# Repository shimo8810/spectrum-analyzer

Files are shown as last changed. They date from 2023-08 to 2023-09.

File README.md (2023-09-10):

# Spectrum Analyzer

This is a stereo 7-band spectrum analyzer utilizing the MSGEQ7.

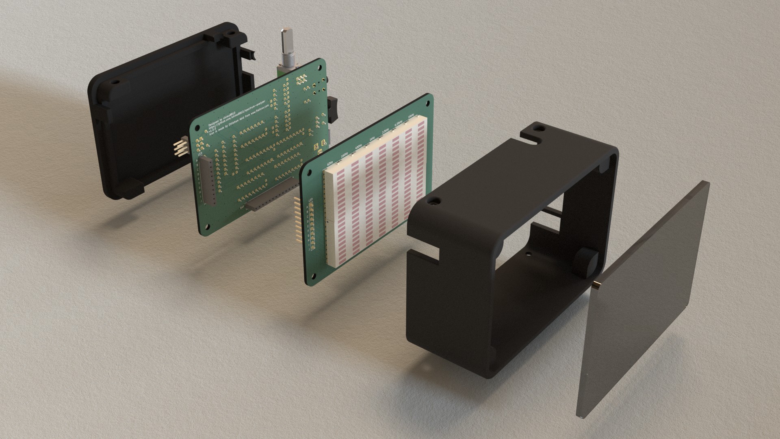
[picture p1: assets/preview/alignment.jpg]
spectrum_analyzer_design


spectrum_analyzer_assembly

## Tools

### LED Matrix Generator

this tool is for generating data for LED matrix.

[LED Matrix Generator Web App](https://shimo8810.github.io/spectrum-analyzer/)
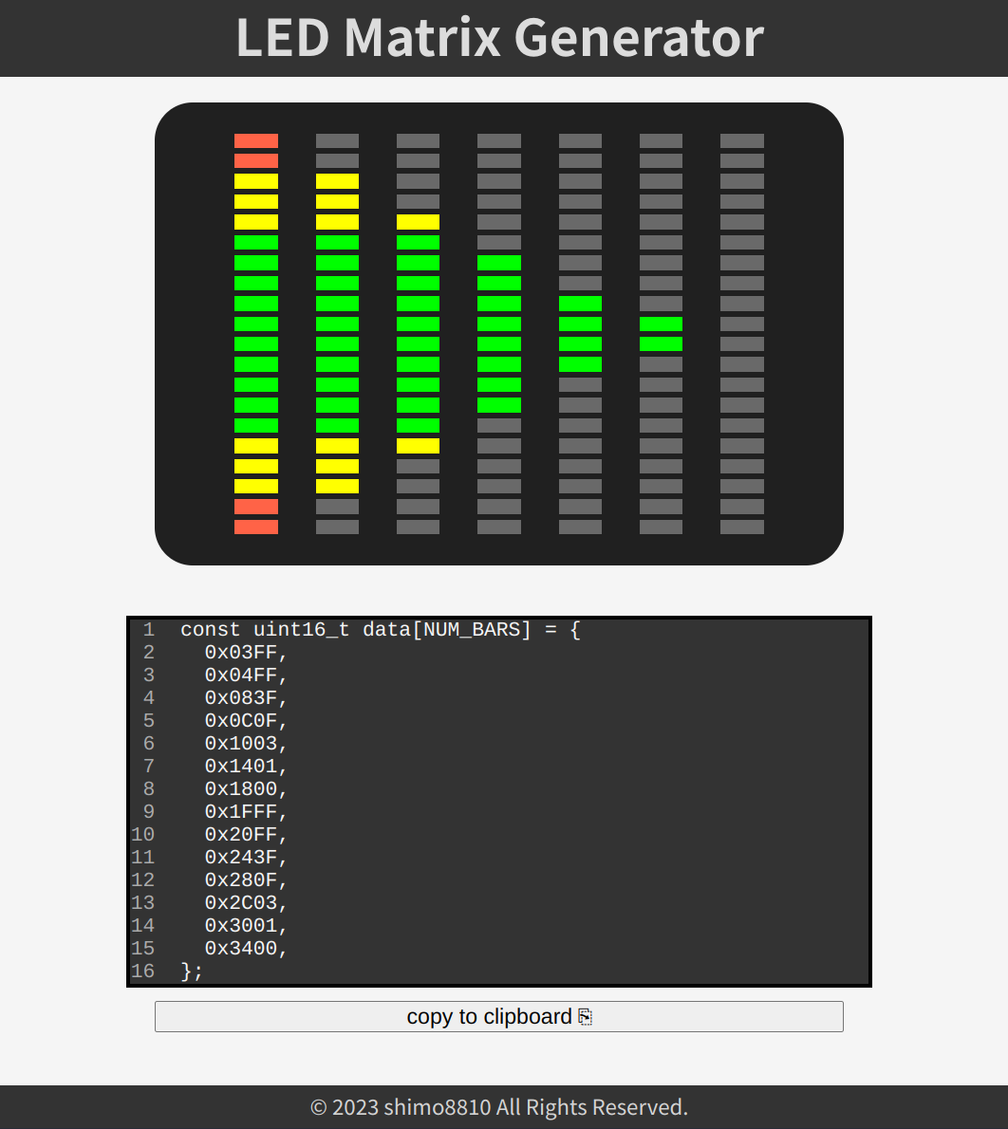
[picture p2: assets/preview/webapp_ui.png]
webapp_ui


## License

- Software: [MIT License](https://choosealicense.com/licenses/mit/)
- Hardware: [CERN Open Hardware License version 2.0](https://choosealicense.com/licenses/cern-ohl-p-2.0/)

## Acknowledgments

- [Equalizer icons created by Ehtisham Abid - Flaticon](https://www.flaticon.com/free-icons/equalizer)

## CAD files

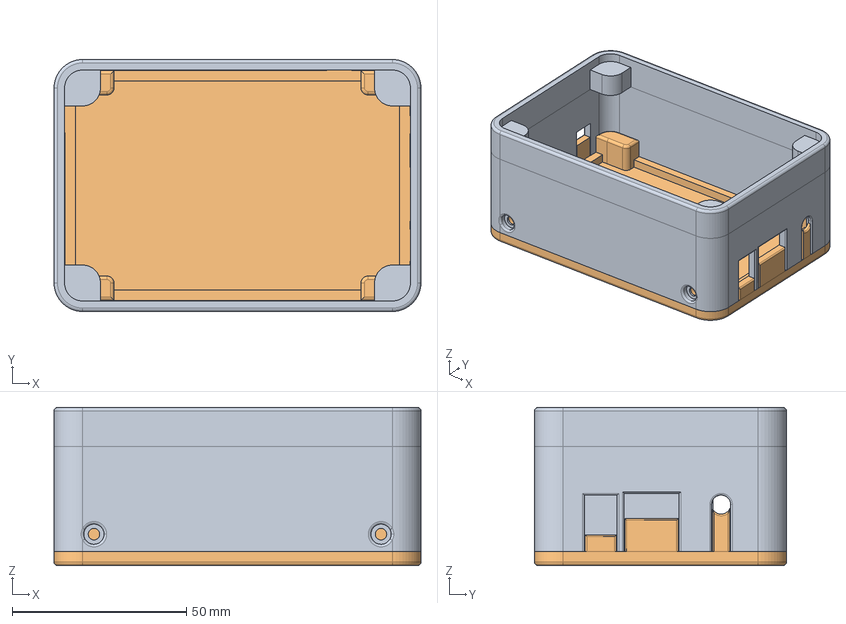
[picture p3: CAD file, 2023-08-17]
3dmodels/spectrum-analyzer.FCStd
105.4 x 72.4 x 45.4 mm
front-body
back-body
Defeatured002

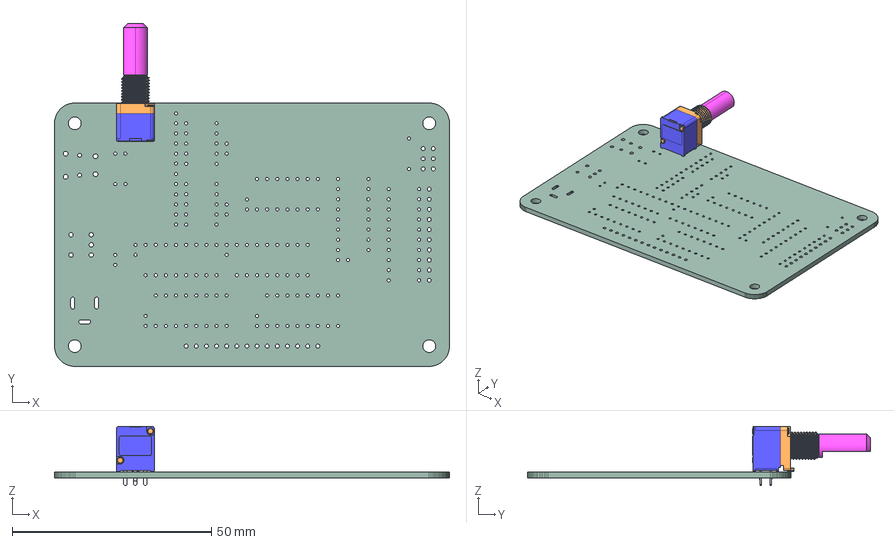
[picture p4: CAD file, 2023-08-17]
assets/spectrum_analyzer_controller.step
99.1 x 86.0 x 14.8 mm
_autosave-spectrum_analyzer_controller PCB

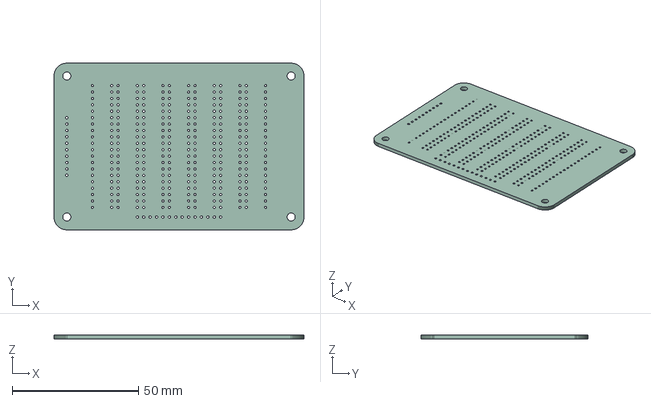
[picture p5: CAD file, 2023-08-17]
assets/spectrum_analyzer_display.step
99.1 x 66.0 x 1.58 mm

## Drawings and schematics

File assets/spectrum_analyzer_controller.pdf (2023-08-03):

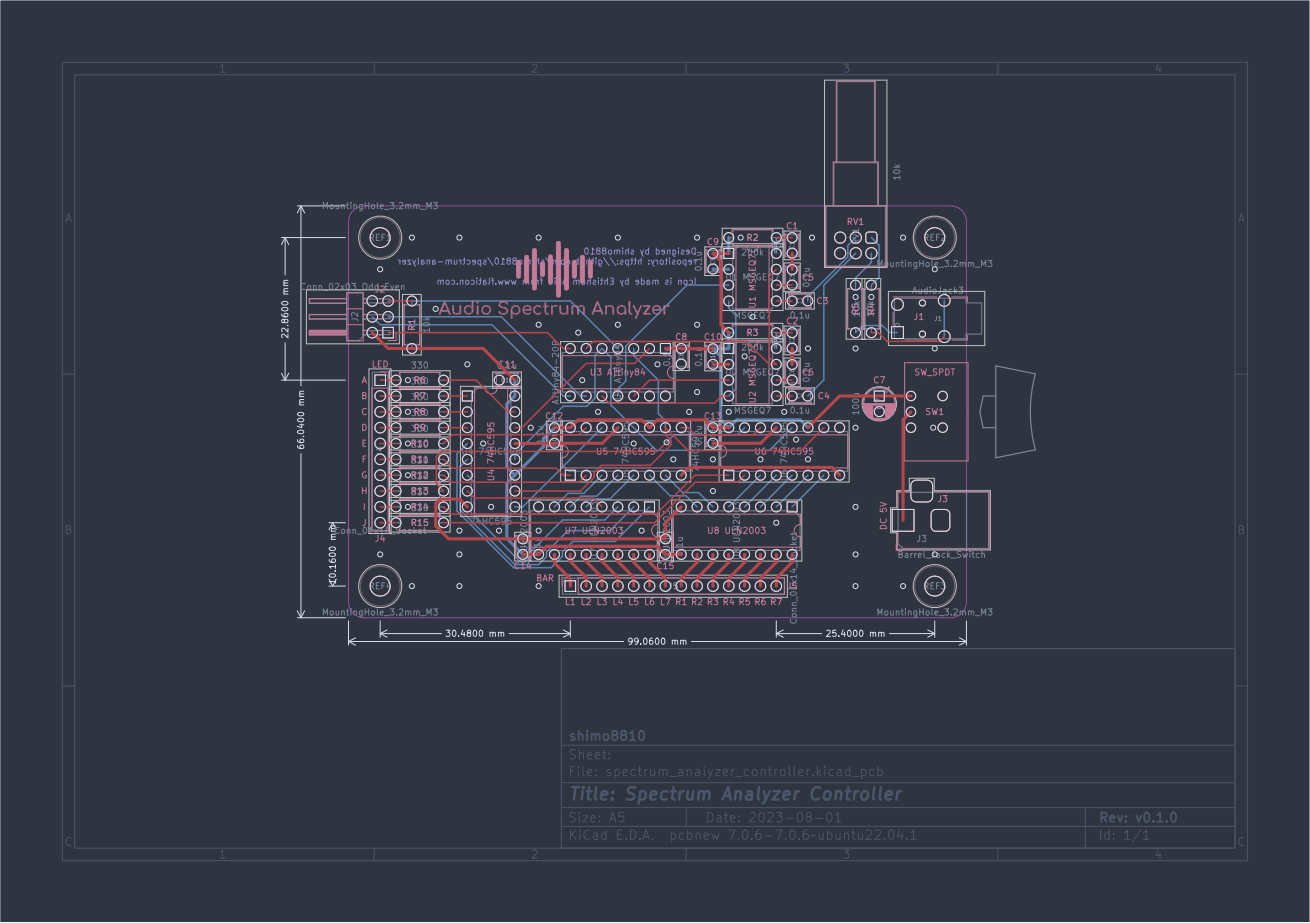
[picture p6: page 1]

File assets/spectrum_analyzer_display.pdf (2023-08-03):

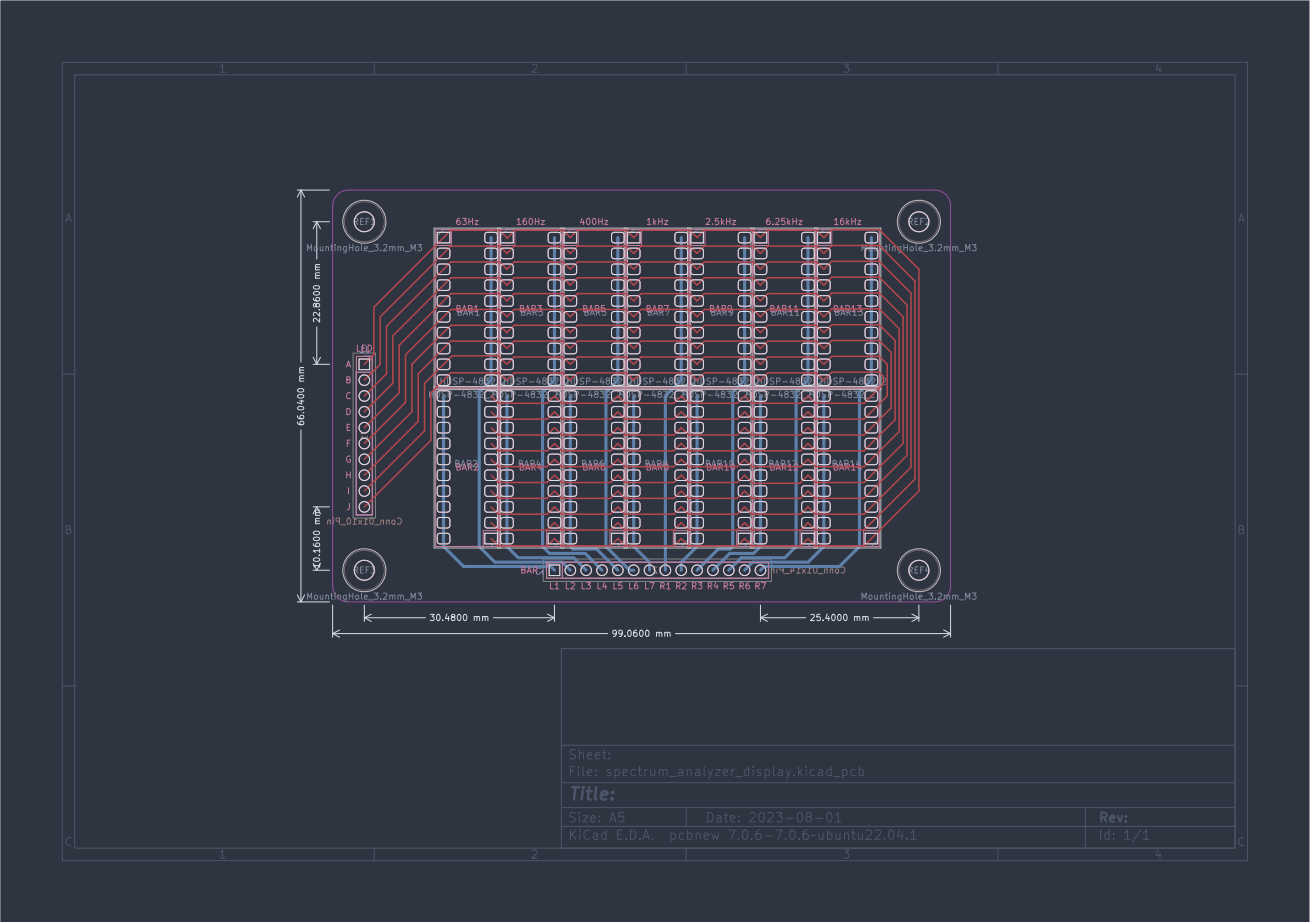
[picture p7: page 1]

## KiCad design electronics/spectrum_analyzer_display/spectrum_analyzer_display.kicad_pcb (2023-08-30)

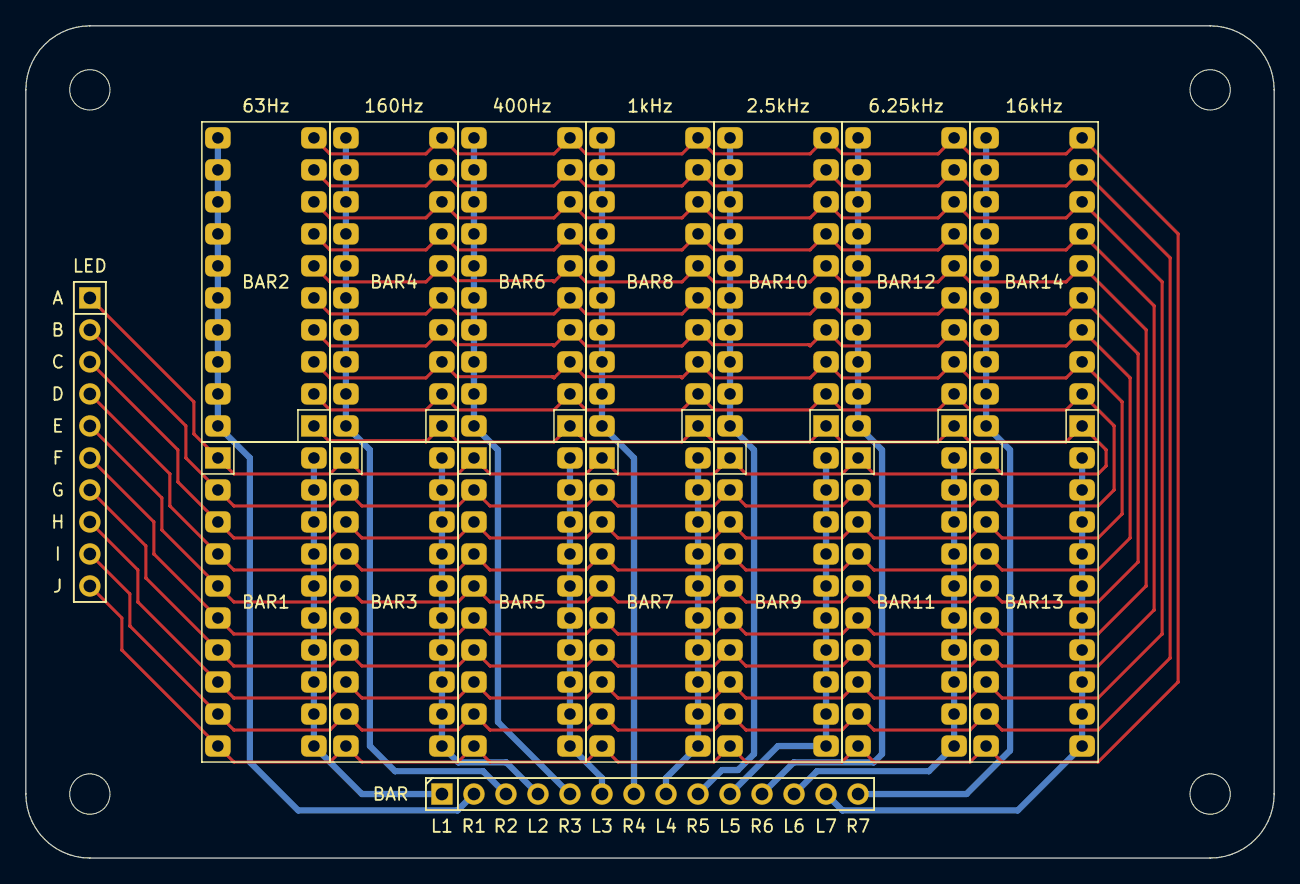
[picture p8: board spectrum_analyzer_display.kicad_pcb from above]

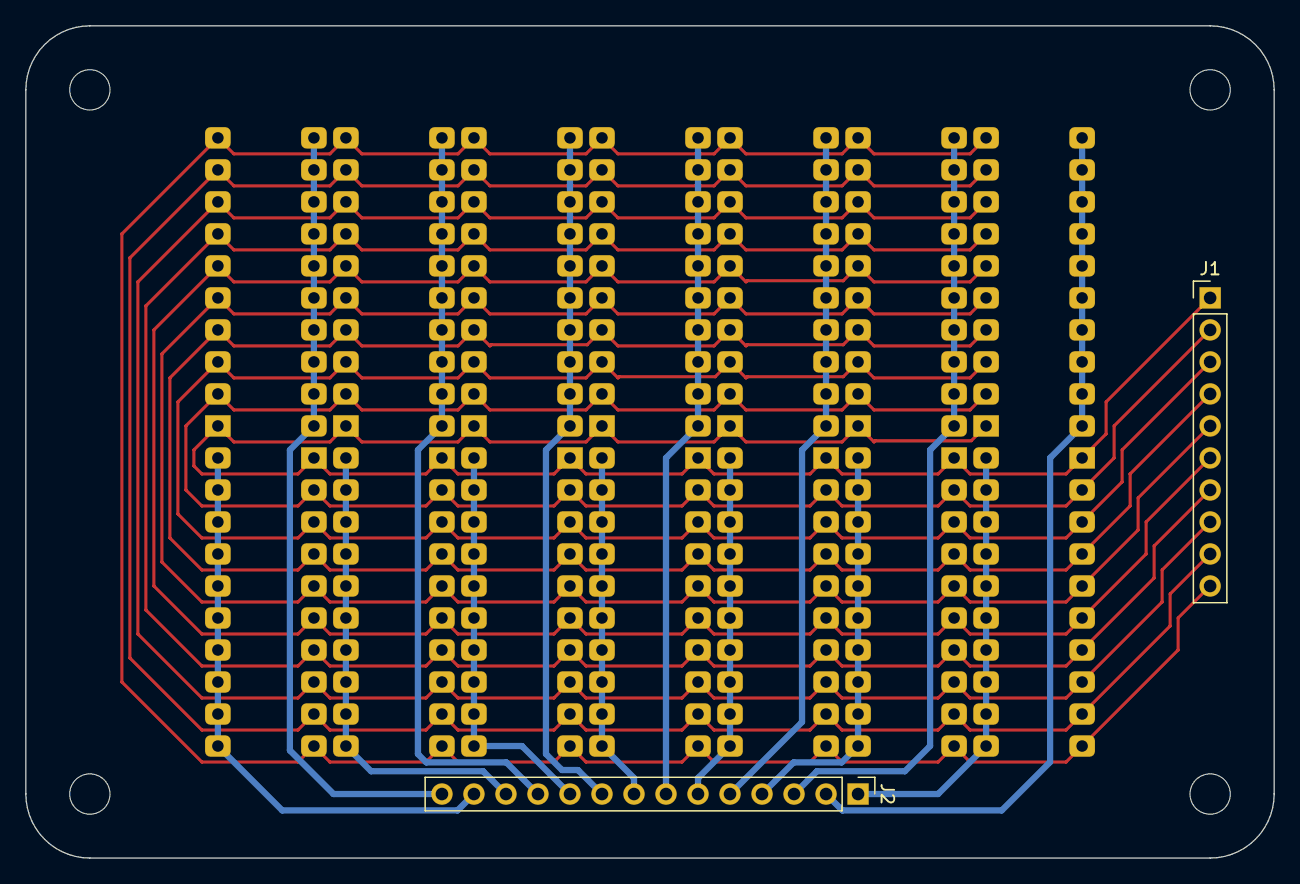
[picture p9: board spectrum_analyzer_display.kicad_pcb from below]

Board: 2 copper layers, 99.1 x 66.0 mm, 20 parts (2 on the bottom side), 24 nets.

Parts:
BAR1, BAR2, BAR3, BAR4, BAR5, BAR6, BAR7, BAR8, BAR9, BAR10, BAR11, BAR12, BAR13, BAR14: HDSP-4832_2; SP_HDSP-4832
J1: Conn_01x10_Pin; PinHeader_1x10_P2.54mm_Vertical
J2: Conn_01x14_Pin; PinHeader_1x14_P2.54mm_Vertical
REF1, REF2, REF3, REF4: MountingHole_3.2mm_M3

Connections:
/A: BAR1.1 (A), BAR2.1 (A), BAR3.1 (A), BAR4.1 (A), BAR5.1 (A), BAR6.1 (A), BAR7.1 (A), BAR8.1 (A), BAR9.1 (A), BAR10.1 (A), BAR11.1 (A), BAR12.1 (A), BAR13.1 (A), BAR14.1 (A), J1.1
/B: BAR1.2 (A), BAR2.2 (A), BAR3.2 (A), BAR4.2 (A), BAR5.2 (A), BAR6.2 (A), BAR7.2 (A), BAR8.2 (A), BAR9.2 (A), BAR10.2 (A), BAR11.2 (A), BAR12.2 (A), BAR13.2 (A), BAR14.2 (A), J1.2
/C: BAR1.3 (A), BAR2.3 (A), BAR3.3 (A), BAR4.3 (A), BAR5.3 (A), BAR6.3 (A), BAR7.3 (A), BAR8.3 (A), BAR9.3 (A), BAR10.3 (A), BAR11.3 (A), BAR12.3 (A), BAR13.3 (A), BAR14.3 (A), J1.3
/D: BAR1.4 (A), BAR2.4 (A), BAR3.4 (A), BAR4.4 (A), BAR5.4 (A), BAR6.4 (A), BAR7.4 (A), BAR8.4 (A), BAR9.4 (A), BAR10.4 (A), BAR11.4 (A), BAR12.4 (A), BAR13.4 (A), BAR14.4 (A), J1.4
/E: BAR1.5 (A), BAR2.5 (A), BAR3.5 (A), BAR4.5 (A), BAR5.5 (A), BAR6.5 (A), BAR7.5 (A), BAR8.5 (A), BAR9.5 (A), BAR10.5 (A), BAR11.5 (A), BAR12.5 (A), BAR13.5 (A), BAR14.5 (A), J1.5
/F: BAR1.6 (A), BAR2.6 (A), BAR3.6 (A), BAR4.6 (A), BAR5.6 (A), BAR6.6 (A), BAR7.6 (A), BAR8.6 (A), BAR9.6 (A), BAR10.6 (A), BAR11.6 (A), BAR12.6 (A), BAR13.6 (A), BAR14.6 (A), J1.6
/G: BAR1.7 (A), BAR2.7 (A), BAR3.7 (A), BAR4.7 (A), BAR5.7 (A), BAR6.7 (A), BAR7.7 (A), BAR8.7 (A), BAR9.7 (A), BAR10.7 (A), BAR11.7 (A), BAR12.7 (A), BAR13.7 (A), BAR14.7 (A), J1.7
/H: BAR1.8 (A), BAR2.8 (A), BAR3.8 (A), BAR4.8 (A), BAR5.8 (A), BAR6.8 (A), BAR7.8 (A), BAR8.8 (A), BAR9.8 (A), BAR10.8 (A), BAR11.8 (A), BAR12.8 (A), BAR13.8 (A), BAR14.8 (A), J1.8
/I: BAR1.9 (A), BAR2.9 (A), BAR3.9 (A), BAR4.9 (A), BAR5.9 (A), BAR6.9 (A), BAR7.9 (A), BAR8.9 (A), BAR9.9 (A), BAR10.9 (A), BAR11.9 (A), BAR12.9 (A), BAR13.9 (A), BAR14.9 (A), J1.9
/J: BAR1.10 (A), BAR2.10 (A), BAR3.10 (A), BAR4.10 (A), BAR5.10 (A), BAR6.10 (A), BAR7.10 (A), BAR8.10 (A), BAR9.10 (A), BAR10.10 (A), BAR11.10 (A), BAR12.10 (A), BAR13.10 (A), BAR14.10 (A), J1.10
/LEFT_1: BAR1.11 (K), BAR1.12 (K), BAR1.13 (K), BAR1.14 (K), BAR1.15 (K), BAR1.16 (K), BAR1.17 (K), BAR1.18 (K), BAR1.19 (K), BAR1.20 (K), J2.1
/LEFT_2: BAR3.11 (K), BAR3.12 (K), BAR3.13 (K), BAR3.14 (K), BAR3.15 (K), BAR3.16 (K), BAR3.17 (K), BAR3.18 (K), BAR3.19 (K), BAR3.20 (K), J2.4
/LEFT_3: BAR5.11 (K), BAR5.12 (K), BAR5.13 (K), BAR5.14 (K), BAR5.15 (K), BAR5.16 (K), BAR5.17 (K), BAR5.18 (K), BAR5.19 (K), BAR5.20 (K), J2.6
/LEFT_4: BAR7.11 (K), BAR7.12 (K), BAR7.13 (K), BAR7.14 (K), BAR7.15 (K), BAR7.16 (K), BAR7.17 (K), BAR7.18 (K), BAR7.19 (K), BAR7.20 (K), J2.8
/LEFT_5: BAR9.11 (K), BAR9.12 (K), BAR9.13 (K), BAR9.14 (K), BAR9.15 (K), BAR9.16 (K), BAR9.17 (K), BAR9.18 (K), BAR9.19 (K), BAR9.20 (K), J2.10
/LEFT_6: BAR11.11 (K), BAR11.12 (K), BAR11.13 (K), BAR11.14 (K), BAR11.15 (K), BAR11.16 (K), BAR11.17 (K), BAR11.18 (K), BAR11.19 (K), BAR11.20 (K), J2.12
/LEFT_7: BAR13.11 (K), BAR13.12 (K), BAR13.13 (K), BAR13.14 (K), BAR13.15 (K), BAR13.16 (K), BAR13.17 (K), BAR13.18 (K), BAR13.19 (K), BAR13.20 (K), J2.13
/RIGHT_1: BAR2.11 (K), BAR2.12 (K), BAR2.13 (K), BAR2.14 (K), BAR2.15 (K), BAR2.16 (K), BAR2.17 (K), BAR2.18 (K), BAR2.19 (K), BAR2.20 (K), J2.2
/RIGHT_2: BAR4.11 (K), BAR4.12 (K), BAR4.13 (K), BAR4.14 (K), BAR4.15 (K), BAR4.16 (K), BAR4.17 (K), BAR4.18 (K), BAR4.19 (K), BAR4.20 (K), J2.3
/RIGHT_3: BAR6.11 (K), BAR6.12 (K), BAR6.13 (K), BAR6.14 (K), BAR6.15 (K), BAR6.16 (K), BAR6.17 (K), BAR6.18 (K), BAR6.19 (K), BAR6.20 (K), J2.5
/RIGHT_4: BAR8.11 (K), BAR8.12 (K), BAR8.13 (K), BAR8.14 (K), BAR8.15 (K), BAR8.16 (K), BAR8.17 (K), BAR8.18 (K), BAR8.19 (K), BAR8.20 (K), J2.7
/RIGHT_5: BAR10.11 (K), BAR10.12 (K), BAR10.13 (K), BAR10.14 (K), BAR10.15 (K), BAR10.16 (K), BAR10.17 (K), BAR10.18 (K), BAR10.19 (K), BAR10.20 (K), J2.9
/RIGHT_6: BAR12.11 (K), BAR12.12 (K), BAR12.13 (K), BAR12.14 (K), BAR12.15 (K), BAR12.16 (K), BAR12.17 (K), BAR12.18 (K), BAR12.19 (K), BAR12.20 (K), J2.11
/RIGHT_7: BAR14.11 (K), BAR14.12 (K), BAR14.13 (K), BAR14.14 (K), BAR14.15 (K), BAR14.16 (K), BAR14.17 (K), BAR14.18 (K), BAR14.19 (K), BAR14.20 (K), J2.14

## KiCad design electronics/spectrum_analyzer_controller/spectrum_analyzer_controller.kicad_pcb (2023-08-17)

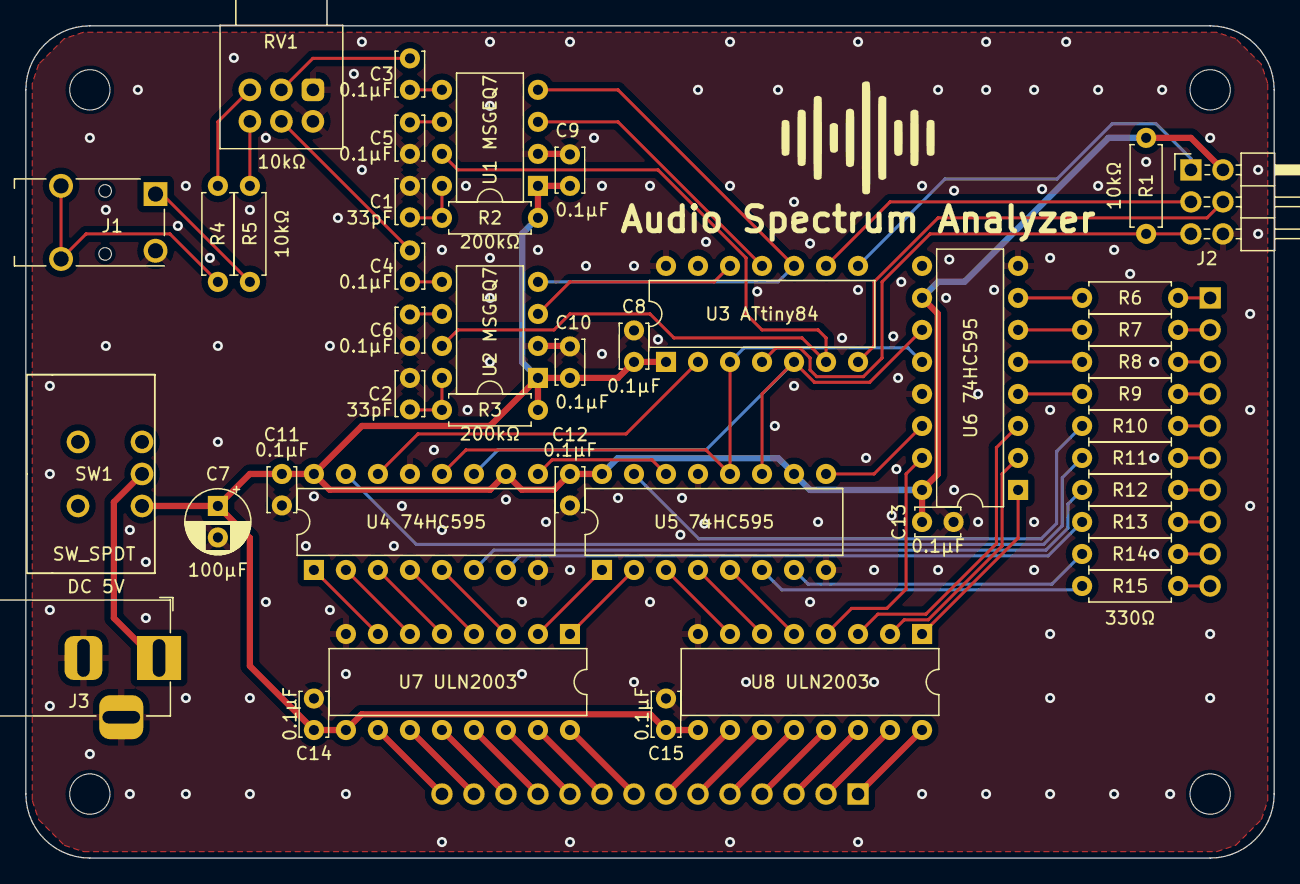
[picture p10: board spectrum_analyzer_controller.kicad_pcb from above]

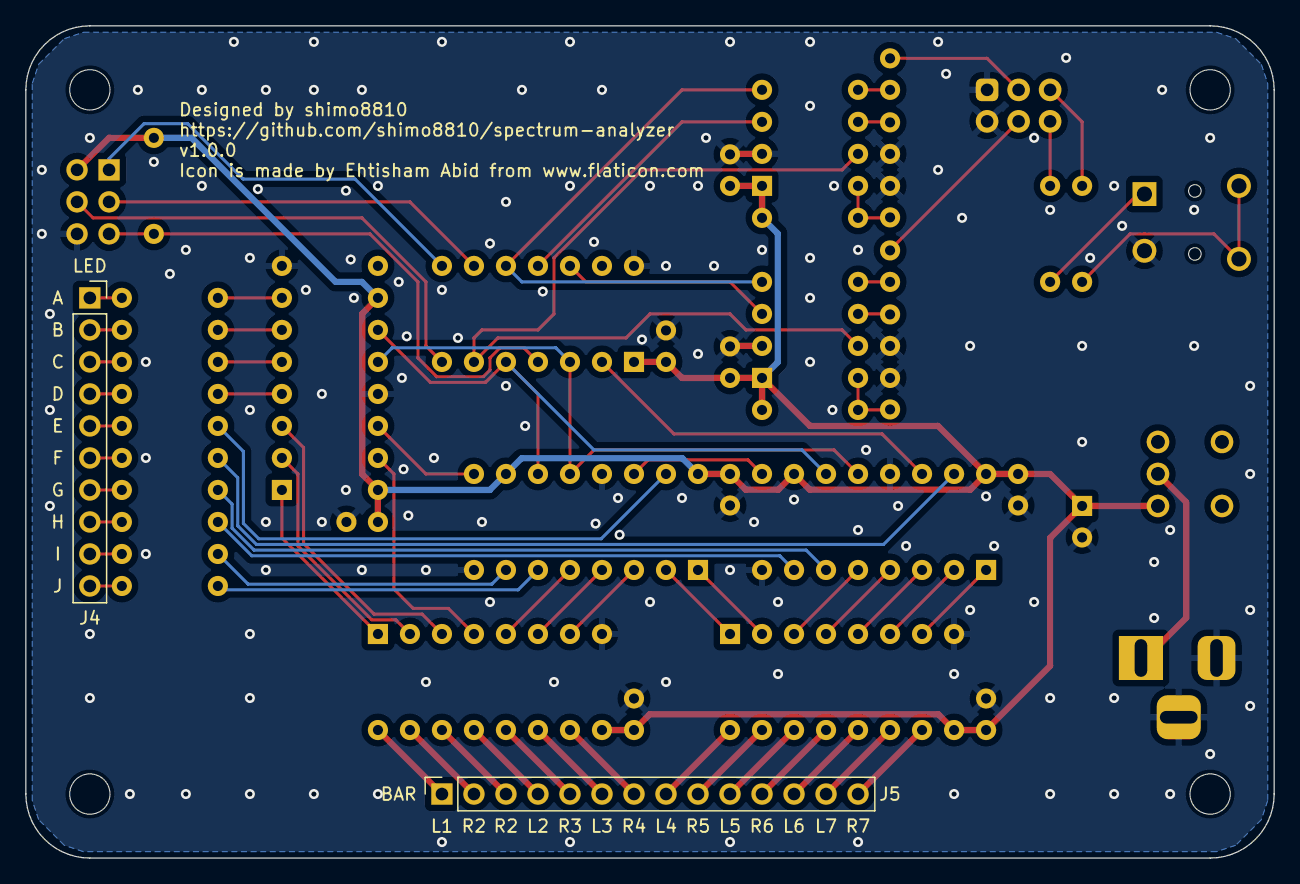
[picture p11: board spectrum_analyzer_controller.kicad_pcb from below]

Board: 2 copper layers, 99.1 x 66.0 mm, 50 parts (2 on the bottom side), 76 nets.

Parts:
C1, C2: 33p; C_Disc_D3.4mm_W2.1mm_P2.50mm
C3, C4, C5, C6, C8, C9, C10, C11, C12, C13, C14, C15: 0.1u; C_Disc_D3.4mm_W2.1mm_P2.50mm
C7: 100u; CP_Radial_D5.0mm_P2.50mm
G1: LOGO; equalizer_icon
J1: AudioJack3; Jack_3.5mm_Switronic_ST-005-G_horizontal
J2: Conn_02x03_Odd_Even; PinHeader_2x03_P2.54mm_Horizontal
J3: Barrel_Jack_Switch; BarrelJack_Horizontal
J4: Conn_01x10_Socket; PinSocket_1x10_P2.54mm_Vertical
J5: Conn_01x14_Socket; PinSocket_1x14_P2.54mm_Vertical
R1, R4, R5: 10k; SP_R_Axial_DIN0207_L6.3mm_D2.5mm_P7.62mm_Horizontal
R2, R3: 200k; SP_R_Axial_DIN0207_L6.3mm_D2.5mm_P7.62mm_Horizontal
R6, R7, R8, R9, R10, R11, R12, R13, R14, R15: 330; SP_R_Axial_DIN0207_L6.3mm_D2.5mm_P7.62mm_Horizontal
REF1, REF2, REF3, REF4: MountingHole_3.2mm_M3
RV1: 10k; Potentiometer_Alps_RK097_Dual_Horizontal
SW1: SW_SPDT; 4MS1R202M6QES
U1 MSGEQ7, U2 MSGEQ7: MSGEQ7; DIP-8_W7.62mm
U3 ATtiny84: ATtiny84-20P; DIP-14_W7.62mm
U4 74HC595, U5 74HC595, U6 74HC595: 74HC595; DIP-16_W7.62mm
U7 ULN2003, U8 ULN2003: ULN2003; DIP-16_W7.62mm

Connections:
+5V: C7.1, C8.1, C9.1, C10.1, C11.1, C12.1, C13.1, C14.1, C15.1, J2.2, R1.1, R2.1, R3.1, SW1.1 (A), U1 MSGEQ7.1 (VDD), U2 MSGEQ7.1 (VDD), U3 ATtiny84.1 (VCC), U4 74HC595.10 (~SRCLR), U4 74HC595.16 (VCC), U5 74HC595.10 (~SRCLR), U5 74HC595.16 (VCC), U6 74HC595.10 (~SRCLR), U6 74HC595.16 (VCC), U7 ULN2003.9 (COM), U8 ULN2003.9 (COM)
/GEQ_RESET: U1 MSGEQ7.7 (RESET), U2 MSGEQ7.7 (RESET), U3 ATtiny84.6 (PA7)
/ICSP_CLOCK: J2.3, U3 ATtiny84.9 (PA4)
/ICSP_MISO: J2.1, U3 ATtiny84.8 (PA5)
/ICSP_MOSI: J2.4, U3 ATtiny84.7 (PA6)
/LED_A: R6.1, U6 74HC595.7 (QH)
/LED_B: R7.1, U6 74HC595.6 (QG)
/LED_C: R8.1, U6 74HC595.5 (QF)
/LED_CLOCK: U3 ATtiny84.5 (PB2), U4 74HC595.11 (SRCLK), U5 74HC595.11 (SRCLK), U6 74HC595.11 (SRCLK)
/LED_D: R9.1, U6 74HC595.4 (QE)
/LED_DATA: U3 ATtiny84.2 (XTAL1/PB0), U4 74HC595.14 (SER)
/LED_E: R10.1, U5 74HC595.15 (QA)
/LED_F: R11.1, U4 74HC595.15 (QA)
/LED_G: R12.1, U4 74HC595.6 (QG)
/LED_H: R13.1, U4 74HC595.7 (QH)
/LED_I: R14.1, U5 74HC595.7 (QH)
/LED_J: R15.1, U5 74HC595.6 (QG)
/LED_LATCH: U3 ATtiny84.3 (XTAL2/PB1), U4 74HC595.12 (RCLK), U5 74HC595.12 (RCLK), U6 74HC595.12 (RCLK)
/LEFT_1: J5.1, U8 ULN2003.16 (O1)
/LEFT_2: J5.4, U8 ULN2003.13 (O4)
/LEFT_3: J5.6, U8 ULN2003.11 (O6)
/LEFT_4: J5.8, U7 ULN2003.16 (O1)
/LEFT_5: J5.10, U7 ULN2003.14 (O3)
/LEFT_6: J5.12, U7 ULN2003.12 (O5)
/LEFT_7: J5.13, U7 ULN2003.11 (O6)
/LEFT_IN: C3.1, U1 MSGEQ7.5 (IN)
/LEFT_OUT: U1 MSGEQ7.3 (OUT), U3 ATtiny84.11 (PA2)
/RESET: J2.5, R1.2, U3 ATtiny84.4 (~RESET/PB3)
/RIGHT_1: J5.2, U8 ULN2003.15 (O2)
/RIGHT_2: J5.3, U8 ULN2003.14 (O3)
/RIGHT_3: J5.5, U8 ULN2003.12 (O5)
/RIGHT_4: J5.7, U8 ULN2003.10 (O7)
/RIGHT_5: J5.9, U7 ULN2003.15 (O2)
/RIGHT_6: J5.11, U7 ULN2003.13 (O4)
/RIGHT_7: J5.14, U7 ULN2003.10 (O7)
/RIGHT_IN: C4.1, U2 MSGEQ7.5 (IN)
/RIGHT_OUT: U2 MSGEQ7.3 (OUT), U3 ATtiny84.12 (PA1)
/STROBE: U1 MSGEQ7.4 (STROBE), U2 MSGEQ7.4 (STROBE), U3 ATtiny84.10 (PA3)
GND: C1.2, C2.2, C5.2, C6.2, C7.2, C8.2, C9.2, C10.2, C11.2, C12.2, C13.2, C14.2, C15.2, J1.S, J2.6, J3.2, J3.3, RV1.1, RV1.4, U1 MSGEQ7.2 (VSS), U2 MSGEQ7.2 (VSS), U3 ATtiny84.14 (GND), U4 74HC595.8 (GND), U4 74HC595.13 (~OE), U5 74HC595.8 (GND), U5 74HC595.13 (~OE), U6 74HC595.8 (GND), U6 74HC595.13 (~OE), U7 ULN2003.8 (GND), U8 ULN2003.8 (GND)
unnamed: C3.2, RV1.2
unnamed: C4.2, RV1.5
unnamed: J1.R, R5.1
unnamed: J1.T, R4.2
unnamed: J4.1, R6.2
unnamed: J4.2, R7.2
unnamed: J4.3, R8.2
unnamed: J4.4, R9.2
unnamed: J4.5, R10.2
unnamed: J4.6, R11.2
unnamed: J4.7, R12.2
unnamed: J4.8, R13.2
unnamed: J4.9, R14.2
unnamed: J4.10, R15.2
unnamed: R4.1, RV1.3
unnamed: R5.2, RV1.6
unnamed: C1.1, R2.2, U1 MSGEQ7.8 (CKIN)
unnamed: C5.1, U1 MSGEQ7.6 (GND)
unnamed: C2.1, R3.2, U2 MSGEQ7.8 (CKIN)
unnamed: C6.1, U2 MSGEQ7.6 (GND)
unnamed: U4 74HC595.1 (QB), U7 ULN2003.7 (I7)
unnamed: U4 74HC595.2 (QC), U7 ULN2003.6 (I6)
unnamed: U4 74HC595.3 (QD), U7 ULN2003.5 (I5)
unnamed: U4 74HC595.4 (QE), U7 ULN2003.4 (I4)
unnamed: U4 74HC595.5 (QF), U7 ULN2003.3 (I3)
unnamed: U4 74HC595.9 (QH'), U5 74HC595.14 (SER)
unnamed: U5 74HC595.1 (QB), U7 ULN2003.2 (I2)
unnamed: U5 74HC595.2 (QC), U7 ULN2003.1 (I1)
unnamed: U5 74HC595.3 (QD), U8 ULN2003.7 (I7)
unnamed: U5 74HC595.4 (QE), U8 ULN2003.6 (I6)
unnamed: U5 74HC595.5 (QF), U8 ULN2003.5 (I5)
unnamed: U5 74HC595.9 (QH'), U6 74HC595.14 (SER)
unnamed: U6 74HC595.15 (QA), U8 ULN2003.4 (I4)
unnamed: U6 74HC595.1 (QB), U8 ULN2003.1 (I1)
unnamed: U6 74HC595.2 (QC), U8 ULN2003.2 (I2)
unnamed: U6 74HC595.3 (QD), U8 ULN2003.3 (I3)
VDC: J3.1, SW1.2 (B)

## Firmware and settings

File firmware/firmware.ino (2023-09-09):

// PINOUT
const uint8_t DATA_PIN = 10;
const uint8_t LATCH_PIN = 9;
const uint8_t CLOCK_PIN = 8;
const uint8_t ROUT_PIN = A1;
const uint8_t LOUT_PIN = A2;
const uint8_t STROBE_PIN = 3;
const uint8_t RESET_PIN = 7;

// LED Matrix constants
const uint8_t NUM_LEVEL = 10;
const uint8_t NUM_BAND = 7;
const uint8_t NUM_BARS = NUM_BAND * 2;

// LED Matrix data
uint32_t MATRIX_DATA[NUM_BARS];

// LED Matrix max level
uint8_t MAX_LEVEL[NUM_BARS];
uint8_t MAX_COUNT[NUM_BARS];
uint8_t MAX_DOWN[NUM_BARS];

/**
 * @brief update led matrix using shift register
 *
 * @param data_pin
 * @param latch_pin
 * @param clock_pin
 * @param data
 */
void updateLedMatrix(const uint8_t data_pin, const uint8_t latch_pin,
                     const uint8_t clock_pin, const uint32_t &data) {
  digitalWrite(latch_pin, LOW);
  for (int i = 0; i < (NUM_LEVEL + NUM_BARS); ++i) {
    digitalWrite(data_pin, (data >> i) & 1);
    digitalWrite(clock_pin, HIGH);
    digitalWrite(clock_pin, LOW);
  }
  digitalWrite(latch_pin, HIGH);
}

/**
 * @brief convert data to led matrix format
 *
 * @param data
 * @return uint32_t
 */
uint32_t convertData(const uint16_t data) {
  // LED bar bits position
  static const uint32_t bar_pos[] = {
      0x20, 0x10, 0x400, 0x1000, 0x4000,  0x80000,  0x400000,
      0x40, 0x80, 0x800, 0x2000, 0x40000, 0x100000, 0x200000};

  // LED bits position
  static const uint32_t led_pos[] = {
      0x1, 0x2, 0x4, 0x8, 0x8000, 0x800000, 0x20000, 0x10000, 0x100, 0x200,
  };

  uint32_t bits = bar_pos[data >> NUM_LEVEL];

  for (uint32_t i = 0; i < NUM_LEVEL; ++i) {
    if ((data >> i) & 1) {
      bits += led_pos[i];
    }
  }
  return bits;
}

/**
 * @brief create led matrix data
 *
 * @param level
 * @param bar
 * @return uint32_t
 */
uint32_t createData(const uint8_t level, const uint8_t bar) {
  uint16_t data = (bar << NUM_LEVEL) + (0x03FF >> (NUM_LEVEL - level));

  if (MAX_LEVEL[bar] <= level) {
    // 最大を更新してカウント値と落下状態を更新
    MAX_LEVEL[bar] = level;
    MAX_DOWN[bar] = 0;
    MAX_COUNT[bar] = 0;
  } else if (MAX_LEVEL[bar] && ++MAX_COUNT[bar] >= 10) {
    if (MAX_LEVEL[bar] >= 5) {
      MAX_DOWN[bar] = 1;
    }
    MAX_LEVEL[bar] -= 1;
    MAX_COUNT[bar] = 10;
  }
  if (MAX_LEVEL[bar] >= 5 || (MAX_LEVEL[bar] && MAX_DOWN[bar])) {
    data |= 1 << (MAX_LEVEL[bar] - 1);
  }

  return convertData(data);
}

/**
 * @brief logscale function
 *
 * @param value
 * @return uint8_t
 */
uint8_t logscale(const int &value) {
  static const int lut[] = {141, 168, 201, 243, 296, 362, 446, 552, 685, 852};
  // static const int lut[] = {65, 85, 112, 148, 195, 257, 338, 446, 589,
  // 777};
  uint8_t level = 0;
  for (level = 0; level < NUM_LEVEL; ++level) {
    if (value < lut[level]) {
      break;
    }
  }
  return level;
}

/**
 * @brief setup function
 *
 */
void setup() {
  // setup led matrix
  pinMode(DATA_PIN, OUTPUT);
  pinMode(LATCH_PIN, OUTPUT);
  pinMode(CLOCK_PIN, OUTPUT);

  // clear LED Matrix
  updateLedMatrix(DATA_PIN, LATCH_PIN, CLOCK_PIN, 0);
  delay(100);

  // setup msgeq7
  pinMode(RESET_PIN, OUTPUT);
  pinMode(STROBE_PIN, OUTPUT);

  // init msgeq7
  digitalWrite(STROBE_PIN, LOW);
  delay(1);
  digitalWrite(RESET_PIN, HIGH);
  delay(1);
  digitalWrite(STROBE_PIN, HIGH);
  delay(1);
  digitalWrite(STROBE_PIN, LOW);
  delay(1);
  digitalWrite(RESET_PIN, LOW);
  delay(5);
}

/**
 * @brief loop function
 *
 */
void loop() {
  static uint8_t band = 0;

  // linear scale
  // uint8_t right_level = (uint8_t)(analogRead(ROUT_PIN) / 94);
  // uint8_t left_level = (uint8_t)(analogRead(LOUT_PIN) / 94);

  // read analog data
  uint8_t right_level = logscale(analogRead(ROUT_PIN));
  uint8_t left_level = logscale(analogRead(LOUT_PIN));

  digitalWrite(STROBE_PIN, HIGH);
  delayMicroseconds(30);
  digitalWrite(STROBE_PIN, LOW);

  // update led matrix
  MATRIX_DATA[band] = createData(right_level, band);
  MATRIX_DATA[band + NUM_BAND] = createData(left_level, band + NUM_BAND);

  for (uint8_t i = 0; i < NUM_BARS; ++i) {
    updateLedMatrix(DATA_PIN, LATCH_PIN, CLOCK_PIN, MATRIX_DATA[i]);
    delayMicroseconds(10);
  }

  // update band
  band += 1;
  if (band >= NUM_BAND) {
    band = 0;
  }
}

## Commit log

2023-07-25 chore: ignore kicad files
2023-08-03 feat: add shematics
    [spectrum_analyzer.kicad_sch, spectrum_analyzer_controller.kicad_pcb, spectrum_analyzer_controller.kicad_sch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]
2023-08-03 feat: change wire width
    [spectrum_analyzer_controller.kicad_pcb, spectrum_analyzer_display.kicad_pcb]
2023-08-06 feat: add 3d models
    [back-enclosure.FCStd, front-enclosure.FCStd]
2023-08-06 chore: add stl files
    [back-enclosure-Body.stl]
2023-08-17 feat: change pcb layout and enclosure design
    [spectrum-analyzer.FCStd, spectrum_analyzer_controller.kicad_pcb, spectrum_analyzer_controller.kicad_sch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]
2023-08-17 chore: remove files
    [back-enclosure-Body.stl, back-enclosure.FCStd, front-enclosure.FCStd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]
2023-08-30 fix: update incorrect wiring of the circuit
    [spectrum_analyzer_display.kicad_pcb]
2023-09-03 feat: add sample code
2023-09-03 refactor: separete delay and led matrix from main.rs
2023-09-03 feat: add show led by matrix
2023-09-03 feat(wip): test led matrix
2023-09-09 chore: exclude arduino setting and build files from git
2023-09-10 feat: add led-matrix-generator tool
